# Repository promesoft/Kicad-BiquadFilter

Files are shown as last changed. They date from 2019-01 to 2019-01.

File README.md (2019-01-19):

# KicadBiquadFilter
Manually variable stereo filter (BP, HP, LP) in two sections

## Status - Rev A Produced Both sections operational
### Errata
 * Section 2 feedback OpAmp incorrect - has to be bypassed
 * Footprint of Op Amp little too small for the packages in stock
 
### Issues and Notes
Issues

Wishlist for Rev B 
 - should handle connectors and Potmeters on the PCB
 - Potmeters should have optional resistor in series and parallel
 - Section 1 adjustable: R5/6 stereo 100k + 680R and R11/13 stereo 20k + 680R
 - Capacitors as THT 47nF polyprop
 - Focus on Eurorack compatibility
 - Mono filter 
 - VCF option

## Physical Construction
 - 100x100mm
 - Several resistors has been selected as THT components so a Potmeter can be placed instead
 
The board is split in two, joined at the center of the board. Each section is a stereo section that can operate individually.
### Section 1 - State Variable filter and buffer amp
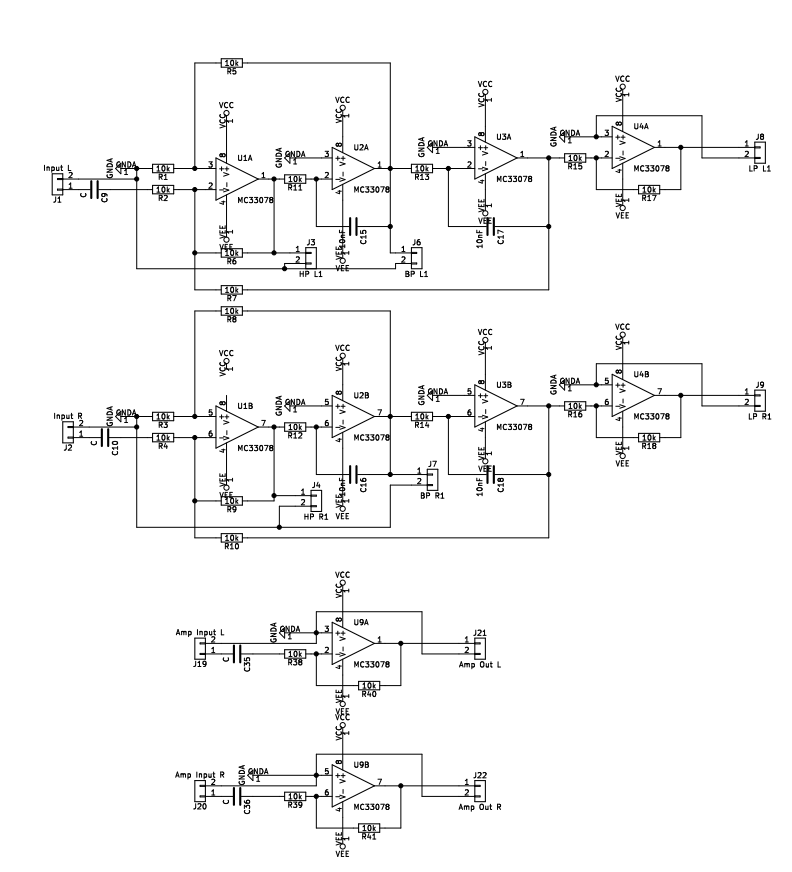
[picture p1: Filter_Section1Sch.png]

### Section 2 - State Variable filter and regulator

## Vital Components
 - Op Amp is chosen as MC33078 but can be selected as long as its pin compatible like (ua833, TL062, TL072, TL082, etc)

### Section 1 Filter components for High Q variable freq and Q:
 - R8 / R5   - 680R + 100k Stereo Pot
 - R10 / R7  - 680R + 100k Stereo Pot
 - R3 / R1   - 47k
 - R4 / R2   - 47k
 - R9 / R6   - 47k
 - R12 / R11 - 680R + 20k Stereo Pot
 - R14 / R13 - 680R + 20k Stereo Pot
 - R16 / C15 - 47nF
 - R18 / C17 - 47nF
 
Fc - 163Hz - 5KHz 

Q - 0,68 - 6,9

## Features
The state variable filter can be configured in different ways and needs to be calculated before the components are selected.

https://www.electronics-tutorials.ws/filter/state-variable-filter.html

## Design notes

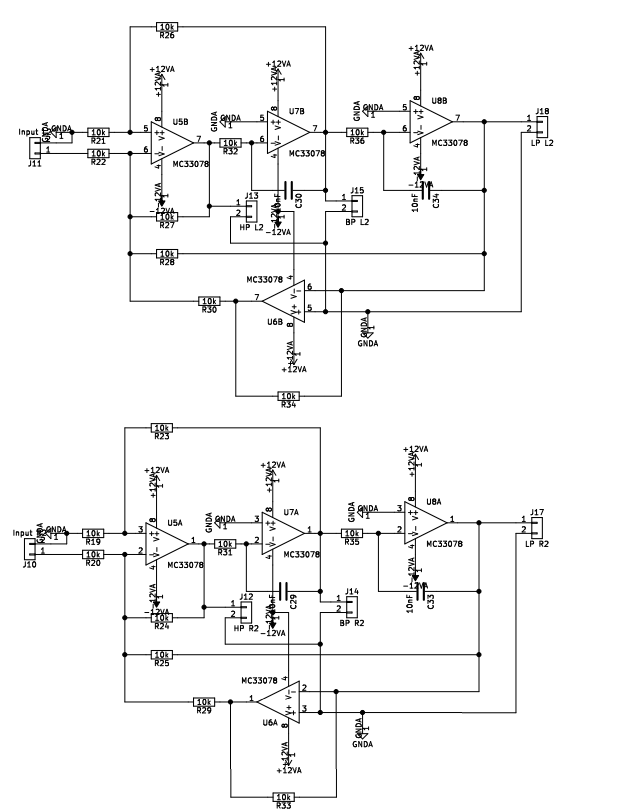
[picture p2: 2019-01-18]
Filter_Section2Sch.png

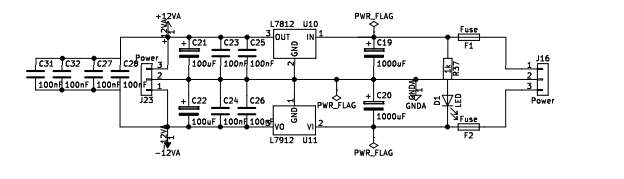
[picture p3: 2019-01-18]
Filter_PowerSection2Sch.png

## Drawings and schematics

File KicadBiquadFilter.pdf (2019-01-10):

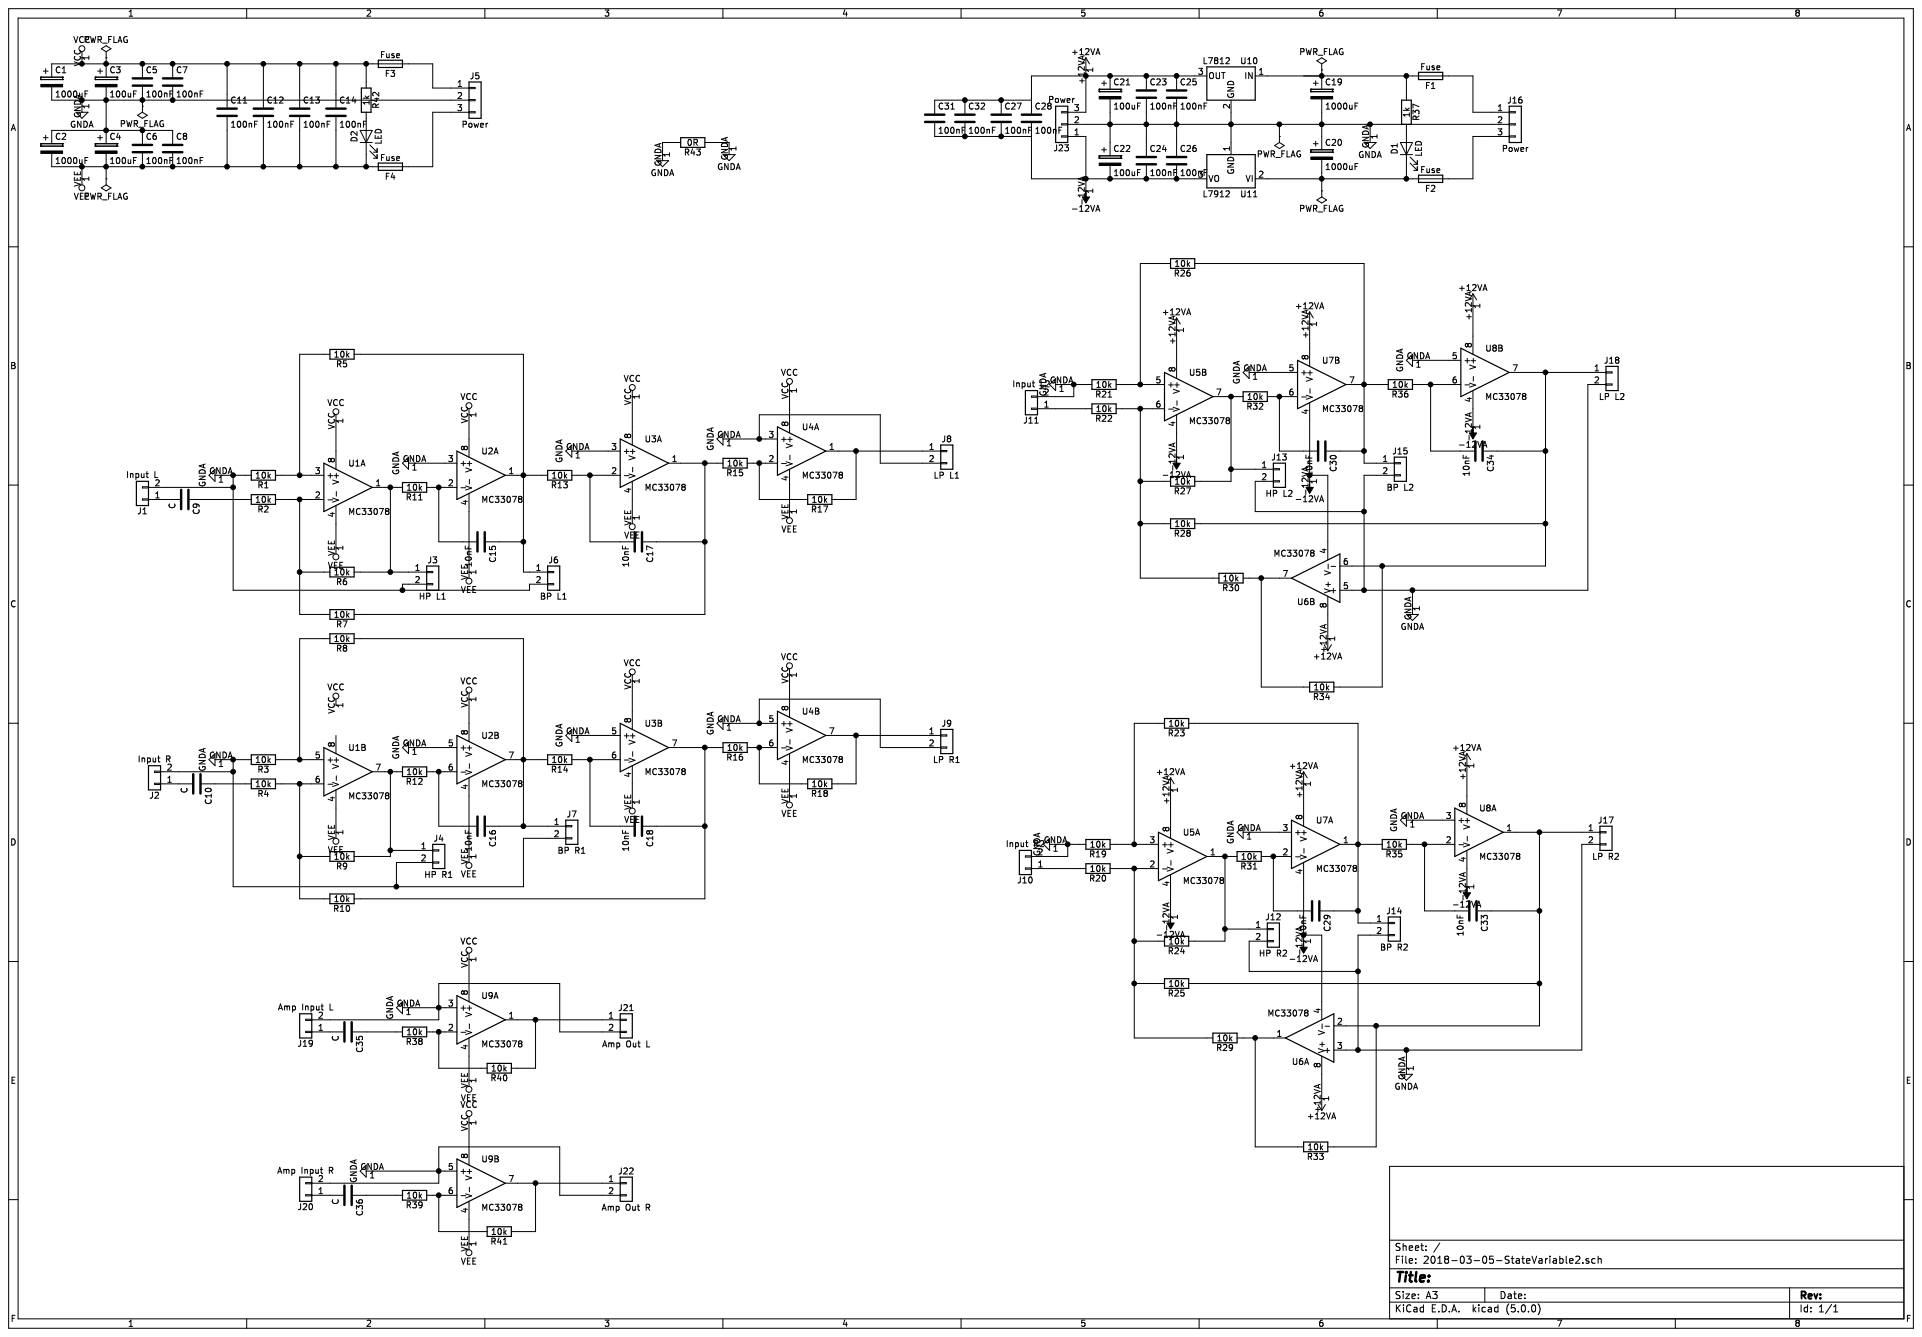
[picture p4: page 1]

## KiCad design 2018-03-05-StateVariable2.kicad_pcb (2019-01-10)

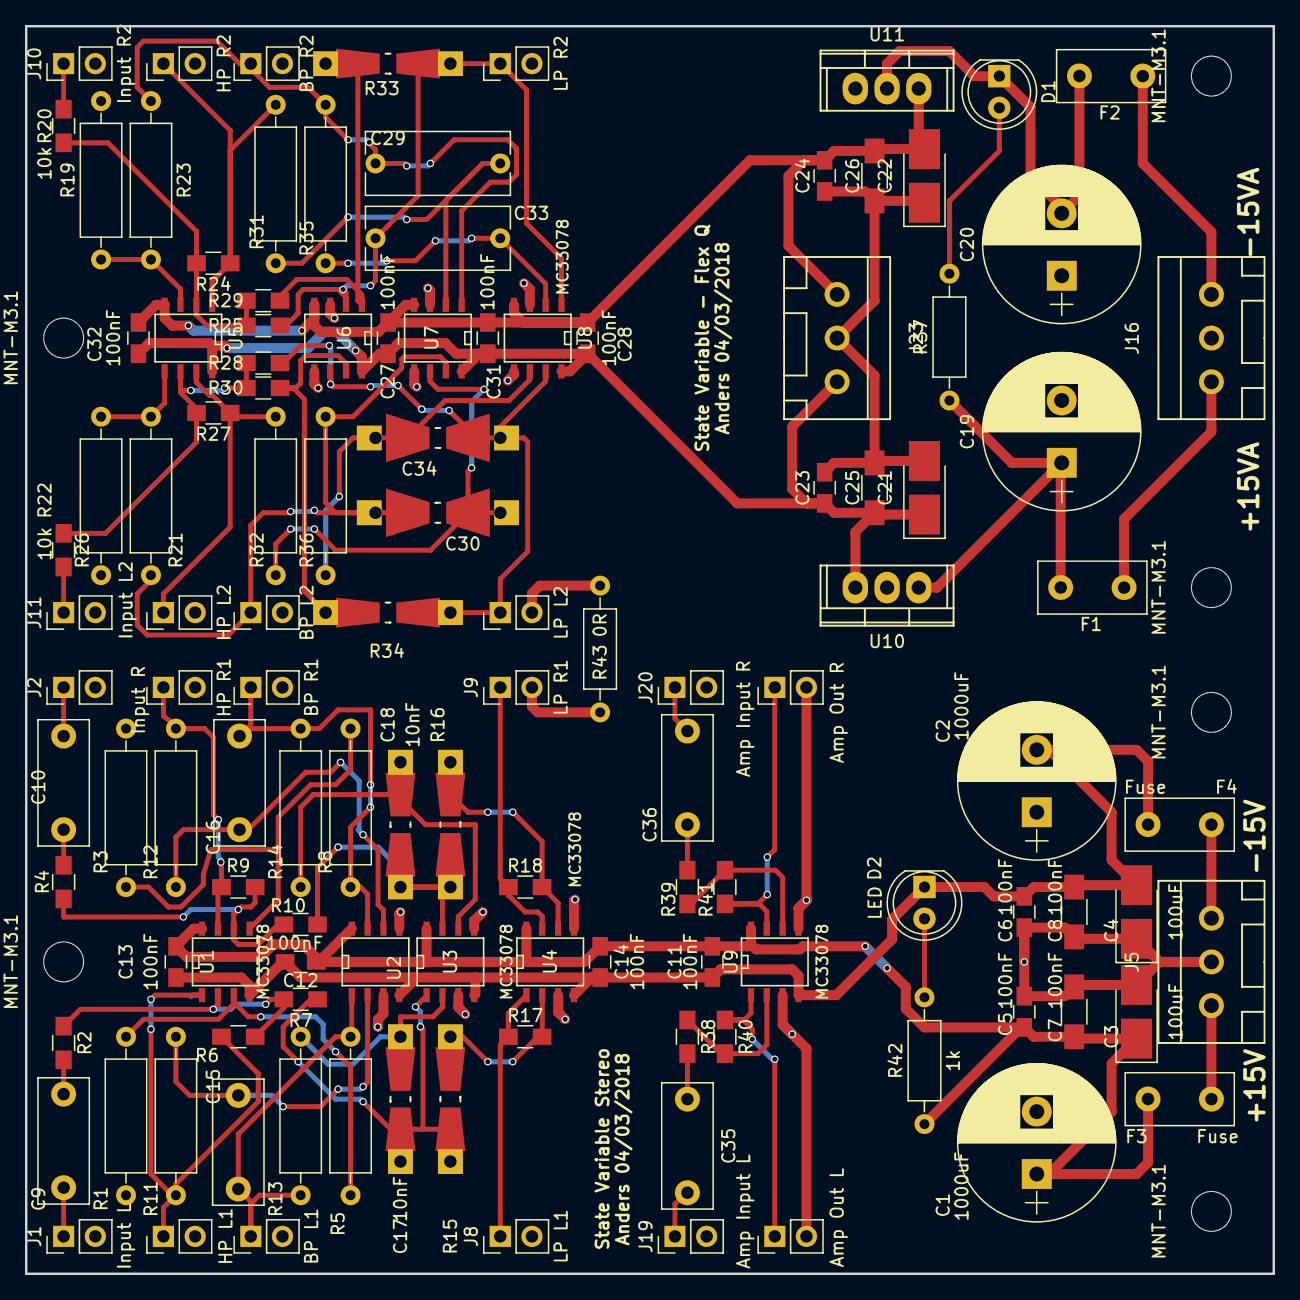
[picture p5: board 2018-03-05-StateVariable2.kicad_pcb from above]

Board: 2 copper layers, 100.0 x 100.0 mm, 125 parts (0 on the bottom side), 61 nets.

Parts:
C1, C2, C19, C20: 1000uF; CP_Radial_D12.5mm_P5.00mm
C3, C4, C21, C22: 100uF; CP_Tantalum_Case-B_EIA-3528-21_Hand
C5, C6, C11, C12, C13, C14, C23, C24, C27, C28, C31, C32: 100nF; C_0805_HandSoldering
C7, C8, C25, C26: 100nF; C_1206_HandSoldering
C9, C10, C35, C36: C; C_Rect_L10.0mm_W4.0mm_P7.50mm_MKS4
C15, C16: 10nF; C_Rect_L10.0mm_W4.0mm_P7.50mm_MKS4
C17, C18: 10nF; Resistor_SMD+THTuniversal_0805to1206_RM10_HandSoldering
C29, C33: 10nF; C_Rect_L11.5mm_W5.0mm_P10.00mm_MKT
C30, C34: 10nF; Resistor_SMD+THTuniversal_0805to2512_RM10_HandSoldering
D1, D2: LED; LED_D5.0mm
F1, F2, F3, F4: Fuse; Fuse_TE5_Littlefuse-395Series
J1: Input L; Pin_Header_Straight_1x02_Pitch2.54mm
J2: Input R; Pin_Header_Straight_1x02_Pitch2.54mm
J3: HP L1; Pin_Header_Straight_1x02_Pitch2.54mm
J4: HP R1; Pin_Header_Straight_1x02_Pitch2.54mm
J5, J16, J23: Power; WAGO_734_3pin_Straight
J6: BP L1; Pin_Header_Straight_1x02_Pitch2.54mm
J7: BP R1; Pin_Header_Straight_1x02_Pitch2.54mm
J8: LP L1; Pin_Header_Straight_1x02_Pitch2.54mm
J9: LP R1; Pin_Header_Straight_1x02_Pitch2.54mm
J10: Input R2; Pin_Header_Straight_1x02_Pitch2.54mm
J11: Input L2; Pin_Header_Straight_1x02_Pitch2.54mm
J12: HP R2; Pin_Header_Straight_1x02_Pitch2.54mm
J13: HP L2; Pin_Header_Straight_1x02_Pitch2.54mm
J14: BP R2; Pin_Header_Straight_1x02_Pitch2.54mm
J15: BP L2; Pin_Header_Straight_1x02_Pitch2.54mm
J17: LP R2; Pin_Header_Straight_1x02_Pitch2.54mm
J18: LP L2; Pin_Header_Straight_1x02_Pitch2.54mm
J19: Amp Input L; Pin_Header_Straight_1x02_Pitch2.54mm
J20: Amp Input R; Pin_Header_Straight_1x02_Pitch2.54mm
J21: Amp Out L; Pin_Header_Straight_1x02_Pitch2.54mm
J22: Amp Out R; Pin_Header_Straight_1x02_Pitch2.54mm
MNT-M3.1, MNT-M3.1#2, MNT-M3.1#3, MNT-M3.1#4, MNT-M3.1#5, MNT-M3.1#6: MountingHole_3.2mm_M3
R1, R3, R5, R8, R11, R12, R13, R14, R19, R21, R23, R26, R31, R32, R35, R36: 10k; R_Axial_DIN0309_L9.0mm_D3.2mm_P12.70mm_Horizontal
R2, R4, R6, R7, R9, R10, R17, R18, R20, R22, R24, R25, R27, R28, R29, R30, R38, R39, R40, R41: 10k; R_0805_HandSoldering
R15, R16, R33, R34: 10k; Resistor_SMD+THTuniversal_0805to1206_RM10_HandSoldering
R37, R42: 1k; R_Axial_DIN0207_L6.3mm_D2.5mm_P10.16mm_Horizontal
R43: 0R; R_Axial_DIN0207_L6.3mm_D2.5mm_P10.16mm_Horizontal
U1, U2, U3, U4, U5, U6, U7, U8, U9: MC33078; SO-8
U10: L7812; TO-220
U11: L7912; TO-220

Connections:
+12VA: C21.1, C23.1, C25.1, C27.1, C28.1, C31.1, C32.1, J23.3, U5.8, U6.8, U7.8, U8.8, U10.3
-12VA: C22.2, C24.2, C26.2, C27.2, C28.2, C31.2, C32.2, J23.1, U5.4, U6.4, U7.4, U8.4, U11.3
GNDA: C1.2, C2.1, C3.2, C4.1, C5.2, C6.1, C7.2, C8.1, C19.2, C20.1, C21.2, C22.1, C23.2, C24.1, C25.2, C26.1, J1.2, J2.2, J3.2, J4.2, J5.2, J6.2, J7.2, J8.2, J9.2, J10.2, J11.2, J12.2, J13.2, J14.2, J15.2, J16.2, J17.2, J18.2, J19.2, J20.2, J21.2, J22.2, J23.2, R1.2, R3.2, R19.2, R21.2, R43.1, R43.2, U2.3, U2.5, U3.3, U3.5, U4.3, U4.5, U6.3, U6.5, U7.3, U7.5, U8.3, U8.5, U9.3, U9.5, U10.2, U11.1
unnamed: C9.1, R2.2
unnamed: C9.2, J1.1
unnamed: C10.1, R4.2
unnamed: C10.2, J2.1
unnamed: C15.1, J6.1, R5.1, R13.2, U2.1
unnamed: C15.2, R11.1, U2.2
unnamed: C16.1, J7.1, R8.1, R14.2, U2.7
unnamed: C16.2, R12.1, U2.6
unnamed: C17.1, R7.1, R15.2, U3.1
unnamed: C17.2, R13.1, U3.2
unnamed: C18.1, R10.1, R16.2, U3.7
unnamed: C18.2, R14.1, U3.6
unnamed: C19.1, F1.2, R37.1, U10.1
unnamed: C20.2, D1.1, F2.2, U11.2
unnamed: C29.1, J14.1, R23.1, R35.2, U7.1
unnamed: C29.2, R31.1, U7.2
unnamed: C30.1, J15.1, R26.1, R36.2, U7.7
unnamed: C30.2, R32.1, U7.6
unnamed: C33.1, J17.1, R25.1, R33.1, U6.2, U8.1
unnamed: C33.2, R35.1, U8.2
unnamed: C34.1, J18.1, R28.1, R34.1, U6.6, U8.7
unnamed: C34.2, R36.1, U8.6
unnamed: C35.1, R38.2
unnamed: C35.2, J19.1
unnamed: C36.1, R39.2
unnamed: C36.2, J20.1
unnamed: D1.2, R37.2
unnamed: D2.2, R42.2
unnamed: F1.1, J16.1
unnamed: F2.1, J16.3
unnamed: F3.1, J5.1
unnamed: F4.1, J5.3
unnamed: J3.1, R6.1, R11.2, U1.1
unnamed: J4.1, R9.1, R12.2, U1.7
unnamed: J8.1, R17.1, U4.1
unnamed: J9.1, R18.1, U4.7
unnamed: J10.1, R20.2
unnamed: J11.1, R22.2
unnamed: J12.1, R24.1, R31.2, U5.1
unnamed: J13.1, R27.1, R32.2, U5.7
unnamed: J21.1, R40.1, U9.1
unnamed: J22.1, R41.1, U9.7
unnamed: R1.1, R5.2, U1.3
unnamed: R2.1, R6.2, R7.2, U1.2
unnamed: R3.1, R8.2, U1.5
unnamed: R4.1, R9.2, R10.2, U1.6
unnamed: R15.1, R17.2, U4.2
unnamed: R16.1, R18.2, U4.6
unnamed: R19.1, R23.2, U5.3
unnamed: R20.1, R24.2, R25.2, R29.2, U5.2
unnamed: R21.1, R26.2, U5.5
unnamed: R22.1, R27.2, R28.2, R30.2, U5.6
unnamed: R29.1, R33.2, U6.1
unnamed: R30.1, R34.2, U6.7
unnamed: R38.1, R40.2, U9.2
unnamed: R39.1, R41.2, U9.6
VCC: C1.1, C3.1, C5.1, C7.1, C11.1, C12.1, C13.1, C14.1, F3.2, R42.1, U1.8, U2.8, U3.8, U4.8, U9.8
VEE: C2.2, C4.2, C6.2, C8.2, C11.2, C12.2, C13.2, C14.2, D2.1, F4.2, U1.4, U2.4, U3.4, U4.4, U9.4

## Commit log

2019-01-10 Init
    Project moved from Statevar2
    [2018-03-05-StateVariable2-2019-01-10-08-10-22.sch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]
2019-01-18 Schematics images
2019-01-19 Readme - filter calc for modular filter
2019-01-19 RevA consolidate
    [2018-03-05-StateVariable2-B.Cu.gbl, 2018-03-05-StateVariable2-B.Mask.gbs, 2018-03-05-StateVariable2-B.Paste.gbp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]
